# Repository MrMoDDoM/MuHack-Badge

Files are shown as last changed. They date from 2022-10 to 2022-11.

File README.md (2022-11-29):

# MuHack-Badge
Official repository for MuHack Badge.

The board features an RP2040 as main microcontroller running micropython.
Its job is to setup and stream data from the Bosh Sensor Hub BHI106B, as well as controlling the LEDs.

```Hardware/``` folder contains the KiCad project

```Software/``` folder contains the BOSS system and the sketch for the ESP32

TODOs:
 - [ ] Connect the interrupt line of BHI to the RP2040
 - [ ] Invert TX/RX of UART between ESP32 and RP2040
 - [ ] Change to a bigger footprint of ESP32 debug port
 - [ ] Maybe add two button for boot sel and reset for the ESP32
 - [ ] Change button battery footprint
 - [ ] Improve silkscreen text size
 - [ ] Add silkscreen label for many things (pinout, battery polarity, etc)
 - [ ] Expose BHI's internal I2C and interrupt line (for future sensors)
 - [ ] Move I2C pull-up resistor
 - [ ] Add led polarity
 - [ ] Remove power inductor (or change to an available one)
 - [ ] Maybe add a way to switch LEDs data line to the ESP32 instead of the RP2040
 - [ ] Docs and code comments
 - [ ] Remove the D16 Schottky Diode from the battery line
 
 Special Thanks to:
 @gcammisa and Paolino

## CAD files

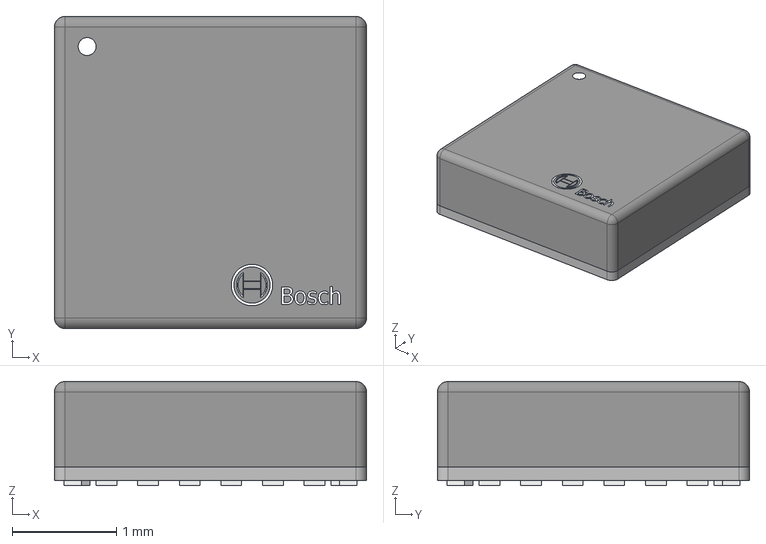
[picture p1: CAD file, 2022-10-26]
Hardware/IC_Bosch Sensortec_BHI160B/eec.models/Bosch_Sensortec_-_BHI160B.step
3.00 x 3.00 x 1.00 mm

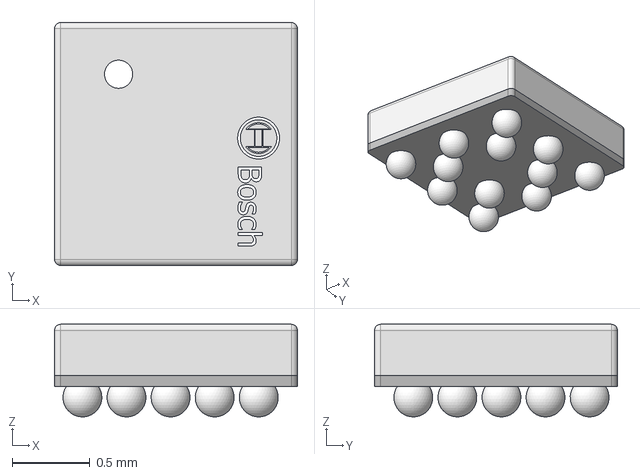
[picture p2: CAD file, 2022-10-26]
Hardware/IC_Bosch Sensortec_BMM150/eec.models/Bosch_Sensortec_-_BMM150.step
1.56 x 1.56 x 0.596 mm

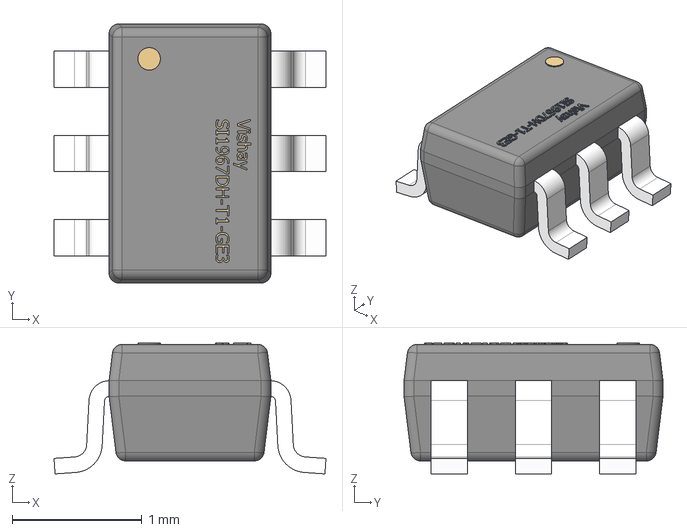
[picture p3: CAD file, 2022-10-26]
Hardware/Trans_Vishay_SI1967DH-T1-GE3/eec.models/Vishay_-_SI1967DH-T1-GE3.step
2.10 x 2.00 x 1.01 mm

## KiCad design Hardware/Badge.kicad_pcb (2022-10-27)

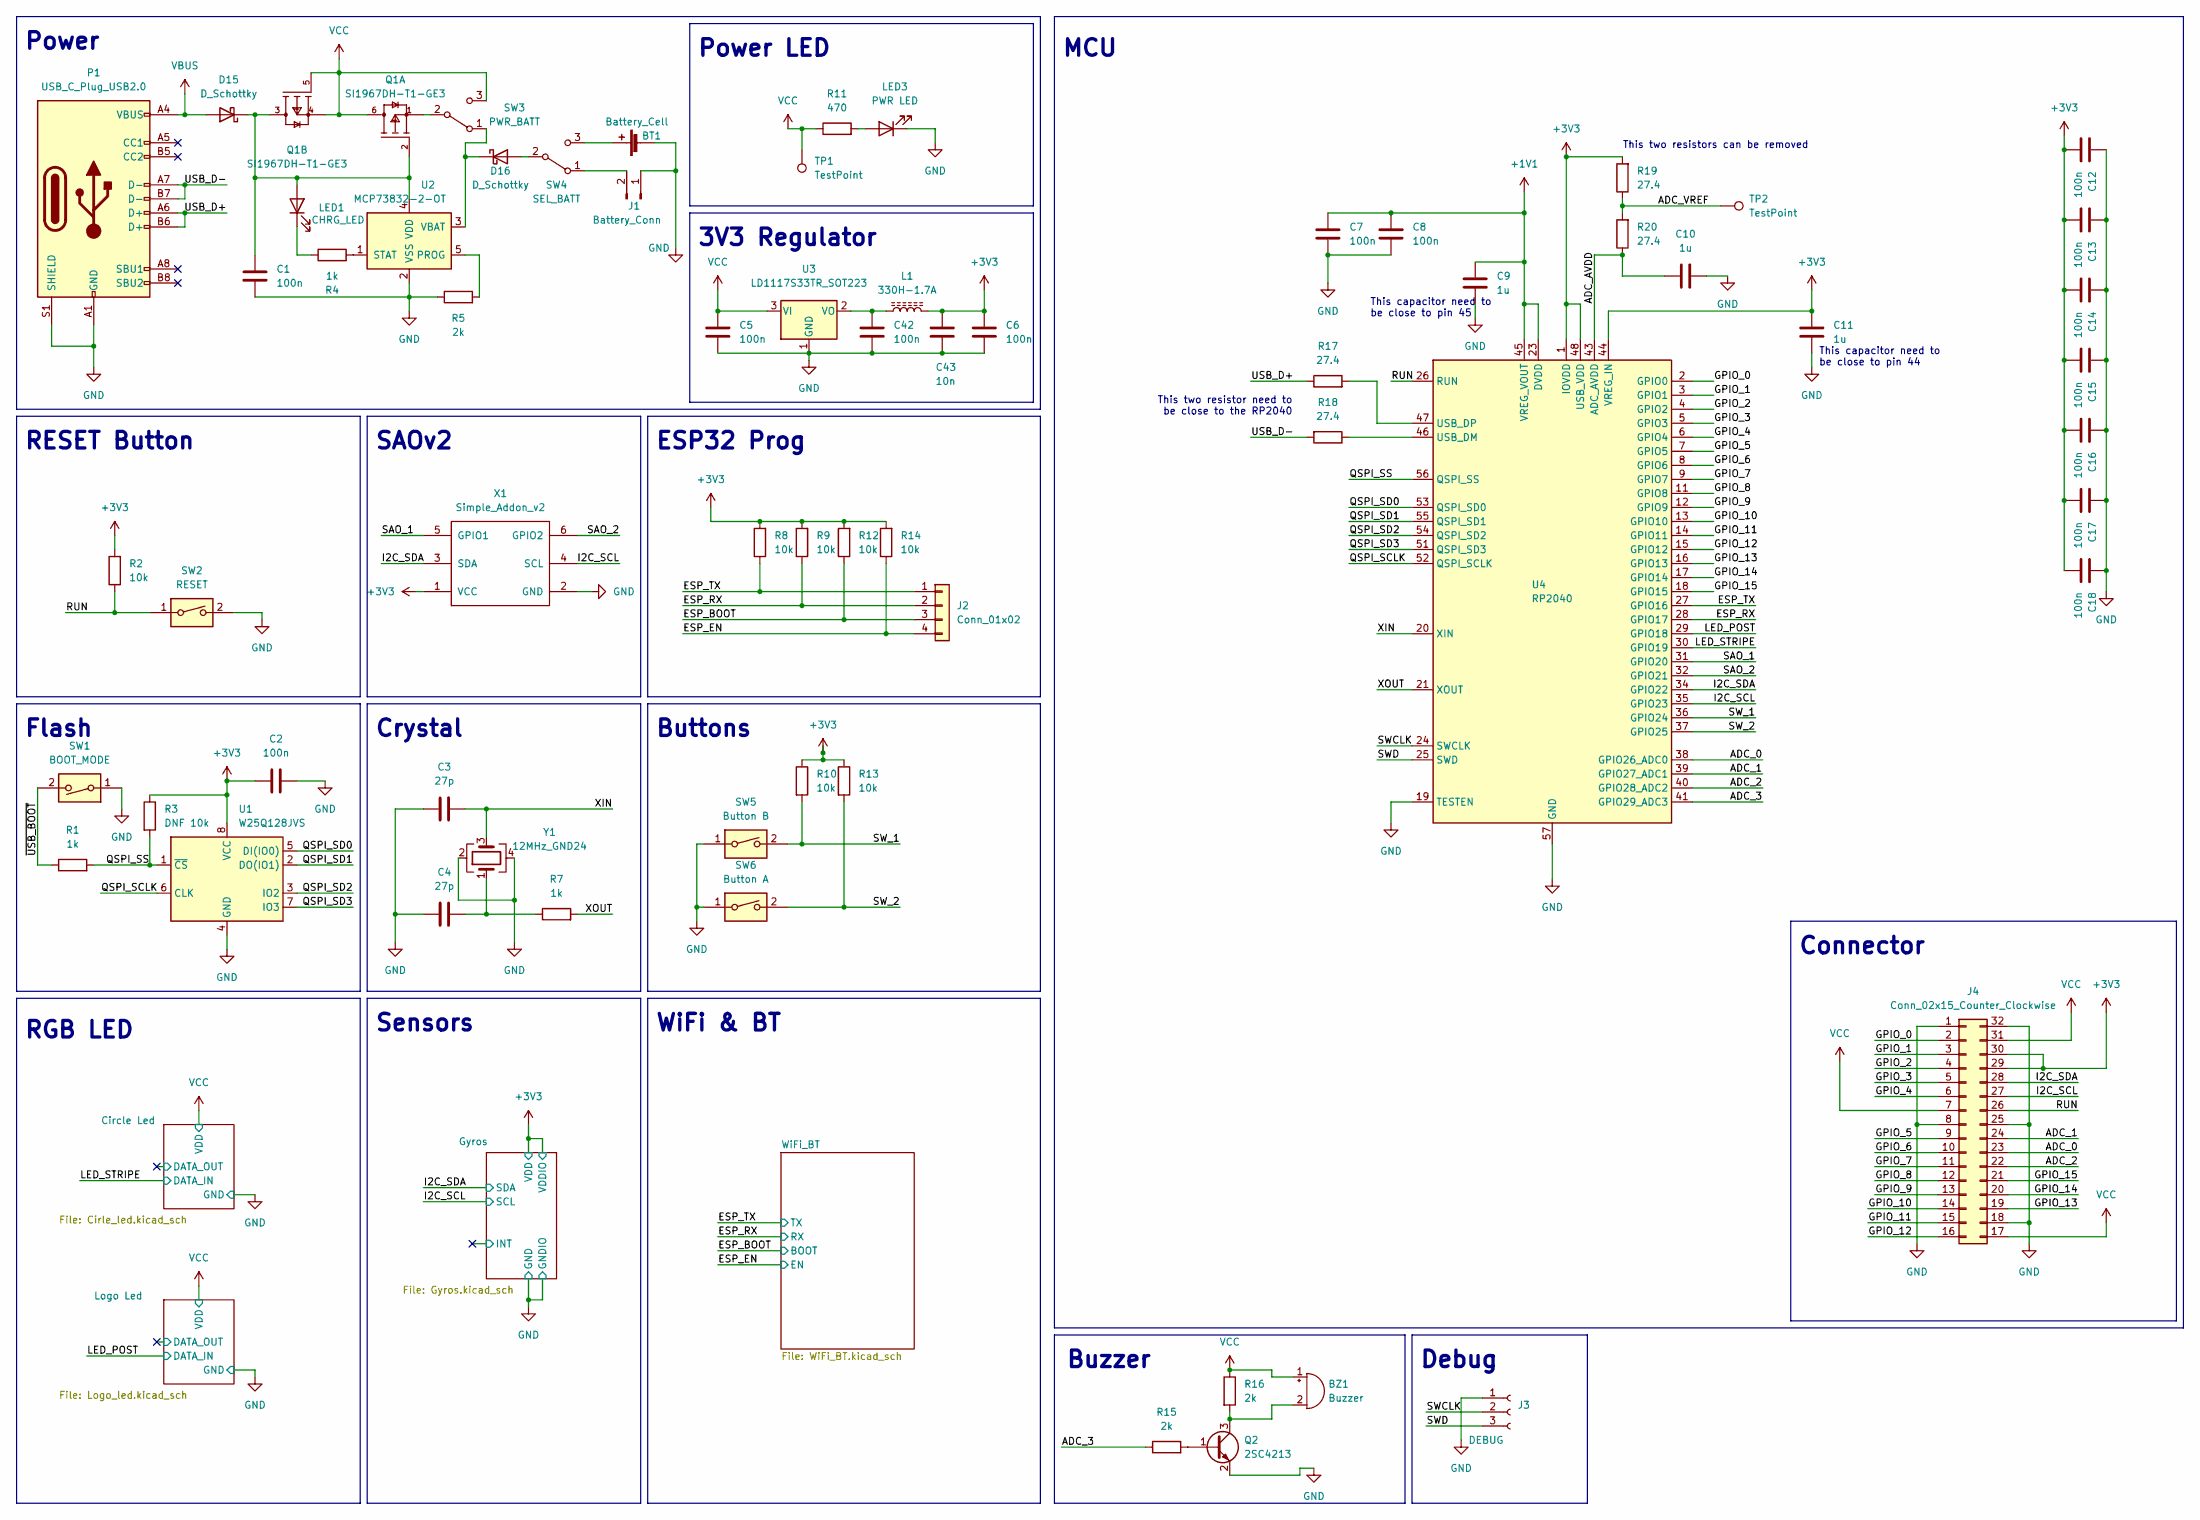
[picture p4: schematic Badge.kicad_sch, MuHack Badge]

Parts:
BT1: Battery_Cell; BatteryHolder_LINX_BAT-HLD-012-SMT
BZ1: Buzzer; Buzzer_Mallory_AST1109MLTRQ
C1, C2, C5, C6, C7, C8, C12, C13, C14, C15, C16, C17, C18, C42: 100n; C_0402_1005Metric
C3, C4: 27p; C_0402_1005Metric
C9, C10, C11: 1u; C_0402_1005Metric
C43: 10n; C_0402_1005Metric
D15, D16: D_Schottky; D_SMA
J1: Battery_Conn; JST_PH_B2B-PH-K_1x02_P2.00mm_Vertical
J2: Conn_01x02; PinSocket_1x04_P1.00mm_Vertical
J3: DEBUG; PinSocket_1x03_P2.54mm_Vertical
J4: Conn_02x15_Counter_Clockwise; PinSocket_2x16_P2.54mm_Vertical
L1: 330H-1.7A; L_0603_1608Metric
LED1: CHRG_LED; LED_0603_1608Metric
LED3: PWR LED; LED_0603_1608Metric
P1: USB_C_Plug_USB2.0; USB_C_Receptacle_Palconn_UTC16-G
Q1: SI1967DH-T1-GE3; Vishay-S-03946-07_2001-B-0; mouser part number 781-SI1967DH-T1-GE3; digikey description MOSFET 2P-CH 20V 1.3A SC70-6
Q2: 2SC4213; SOT-323_SC-70
R1, R4, R7: 1k; R_0402_1005Metric
R2, R8, R9, R10, R12, R13, R14: 10k; R_0402_1005Metric
R3: DNF 10k; R_0402_1005Metric
R5, R15, R16: 2k; R_0402_1005Metric
R11: 470; R_0402_1005Metric
R17, R18, R19, R20: 27.4; R_0402_1005Metric
SW1: BOOT_MODE; TS-1187A-B-A-B
SW2: RESET; TS-1187A-B-A-B
SW3: PWR_BATT; SW_SPDT_CK-JS102011SAQN
SW4: SEL_BATT; SW_SPDT_CK-JS102011SAQN
SW5: Button B; TS-1187A-B-A-B
SW6: Button A; TS-1187A-B-A-B
TP1, TP2: TestPoint; TestPoint_Pad_D1.0mm
U1: W25Q128JVS; SOIC-8_5.23x5.23mm_P1.27mm
U2: MCP73832-2-OT; SOT-23-5
U3: LD1117S33TR_SOT223; SOT-223-3_TabPin2
U4: RP2040; QFN-56-1EP_7x7mm_P0.4mm_EP3.2x3.2mm
X1: Simple_Addon_v2; Simple_Addon_v2-BADGE-2x3
Y1: 12MHz_GND24; Crystal_SMD_3225-4Pin_3.2x2.5mm

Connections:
+1V1: C7.1, C8.1, C9.2, U4.23 (DVDD), U4.45 (VREG_VOUT), U4.50 (DVDD)
+3V3: C2.1, C6.2, C11.1, C12.2, C13.2, C14.2, C15.2, C16.2, C17.2, C18.2, C43.2, J4.29, J4.30, L1.2, R2.2, R3.1, R8.2, R9.2, R10.1, R12.2, R13.1, R14.2, R19.2, U1.8 (VCC), U4.1 (IOVDD), U4.10 (IOVDD), U4.22 (IOVDD), U4.33 (IOVDD), U4.42 (IOVDD), U4.44 (VREG_IN), U4.48 (USB_VDD), U4.49 (IOVDD), X1.1 (VCC); also elsewhere on the board
/ADC_0: J4.23, U4.38 (GPIO26_ADC0)
/ADC_1: J4.24, U4.39 (GPIO27_ADC1)
/ADC_2: J4.22, U4.40 (GPIO28_ADC2)
/ADC_3: R15.1, U4.41 (GPIO29_ADC3)
/ADC_AVDD: C10.1, R20.1, U4.43 (ADC_AVDD)
/ADC_VREF: R19.1, R20.2, TP2.1
/ESP_BOOT: J2.3, R12.1; also elsewhere on the board
/ESP_EN: J2.4, R14.1; also elsewhere on the board
/ESP_RX: J2.2, R9.1, U4.28 (GPIO17); also elsewhere on the board
/ESP_TX: J2.1, R8.1, U4.27 (GPIO16); also elsewhere on the board
/GPIO_0: J4.2, U4.2 (GPIO0)
/GPIO_1: J4.3, U4.3 (GPIO1)
/GPIO_2: J4.4, U4.4 (GPIO2)
/GPIO_3: J4.5, U4.5 (GPIO3)
/GPIO_4: J4.6, U4.6 (GPIO4)
/GPIO_5: J4.9, U4.7 (GPIO5)
/GPIO_6: J4.10, U4.8 (GPIO6)
/GPIO_7: J4.11, U4.9 (GPIO7)
/GPIO_8: J4.12, U4.11 (GPIO8)
/GPIO_9: J4.13, U4.12 (GPIO9)
/GPIO_10: J4.14, U4.13 (GPIO10)
/GPIO_11: J4.15, U4.14 (GPIO11)
/GPIO_12: J4.16, U4.15 (GPIO12)
/GPIO_13: J4.19, U4.16 (GPIO13)
/GPIO_14: J4.20, U4.17 (GPIO14)
/GPIO_15: J4.21, U4.18 (GPIO15)
/I2C_SCL: J4.27, U4.35 (GPIO23), X1.4 (SCL); also elsewhere on the board
/I2C_SDA: J4.28, U4.34 (GPIO22), X1.3 (SDA); also elsewhere on the board
/LED_POST: U4.29 (GPIO18); also elsewhere on the board
/LED_STRIPE: U4.30 (GPIO19); also elsewhere on the board
/QSPI_SCLK: U1.6 (CLK), U4.52 (QSPI_SCLK)
/QSPI_SD0: U1.5 (DI(IO0)), U4.53 (QSPI_SD0)
/QSPI_SD1: U1.2 (DO(IO1)), U4.55 (QSPI_SD1)
/QSPI_SD2: U1.3 (IO2), U4.54 (QSPI_SD2)
/QSPI_SD3: U1.7 (IO3), U4.51 (QSPI_SD3)
/QSPI_SS: R1.2, R3.2, U1.1 (~CS), U4.56 (QSPI_SS)
/RUN: J4.26, R2.1, SW2.1, U4.26 (RUN)
/SAO_1: U4.31 (GPIO20), X1.5 (GPIO1)
/SAO_2: U4.32 (GPIO21), X1.6 (GPIO2)
/SWCLK: J3.2, U4.24 (SWCLK)
/SWD: J3.3, U4.25 (SWD)
/SW_1: R10.2, SW5.2, U4.36 (GPIO24)
/SW_2: R13.2, SW6.2, U4.37 (GPIO25)
/USB_D+: P1.A6 (D+), P1.B6 (D+), R17.1
/USB_D-: P1.A7 (D-), P1.B7 (D-), R18.2
/XIN: C3.2, U4.20 (XIN), Y1.3
/XOUT: R7.2, U4.21 (XOUT)
/~USB_BOOT: R1.1, SW1.2
GND: BT1.2 (-), C1.2, C2.2, C3.1, C4.1, C5.1, C6.1, C7.2, C8.2, C9.1, C10.2, C11.2, C12.1, C13.1, C14.1, C15.1, C16.1, C17.1, C18.1, C42.1, C43.1, J1.1, J3.1, J4.1, J4.8, J4.18, J4.25, J4.32, LED3.1 (K), P1.A1 (GND), P1.A12 (GND), P1.B1 (GND), P1.B12 (GND), P1.S1 (SHIELD), Q2.2 (E), R5.1, SW1.1, SW2.2, SW5.1, SW6.1, U1.4 (GND), U2.2 (VSS), U3.1 (GND), U4.19 (TESTEN), U4.57 (GND), X1.2 (GND), Y1.2, Y1.4; also elsewhere on the board
unnamed: BT1.1 (+), SW4.3 (C)
unnamed: BZ1.2 (+), Q2.3 (C), R16.2
unnamed: C1.1, D15.1 (K), LED1.2 (A), Q1.2 (G1), Q1.3 (D2), U2.4 (VDD)
unnamed: C4.2, R7.1, Y1.1
unnamed: C42.2, L1.1, U3.2 (VO)
unnamed: D16.1 (K), SW3.1 (A), U2.3 (VBAT)
unnamed: D16.2 (A), SW4.2 (B)
unnamed: J1.2, SW4.1 (A)
unnamed: LED1.1 (K), R4.1
unnamed: LED3.2 (A), R11.2
unnamed: Q1.1 (S1), SW3.2 (B)
unnamed: Q2.1 (B), R15.2
unnamed: R4.2, U2.1 (STAT)
unnamed: R5.2, U2.5 (PROG)
unnamed: R17.2, U4.47 (USB_DP)
unnamed: R18.1, U4.46 (USB_DM)
VBUS: D15.2 (A), P1.A4 (VBUS), P1.A9 (VBUS), P1.B4 (VBUS), P1.B9 (VBUS)
VCC: BZ1.1 (-), C5.2, J4.7, J4.17, J4.31, Q1.4 (S2), Q1.5 (G2), Q1.6 (D1), R11.1, R16.1, SW3.3 (C), TP1.1, U3.3 (VI); also elsewhere on the board

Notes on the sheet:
This capacitor need to be close to pin 44
Buttons
Power
This two resistor need to be close to the RP2040
ESP32 Prog
3V3 Regulator
Crystal
Power LED
This capacitor need to be close to pin 45
RESET Button
This two resistors can be removed
WiFi & BT
Connector
SAOv2
Buzzer
Flash
Debug
Sensors
MCU
RGB LED

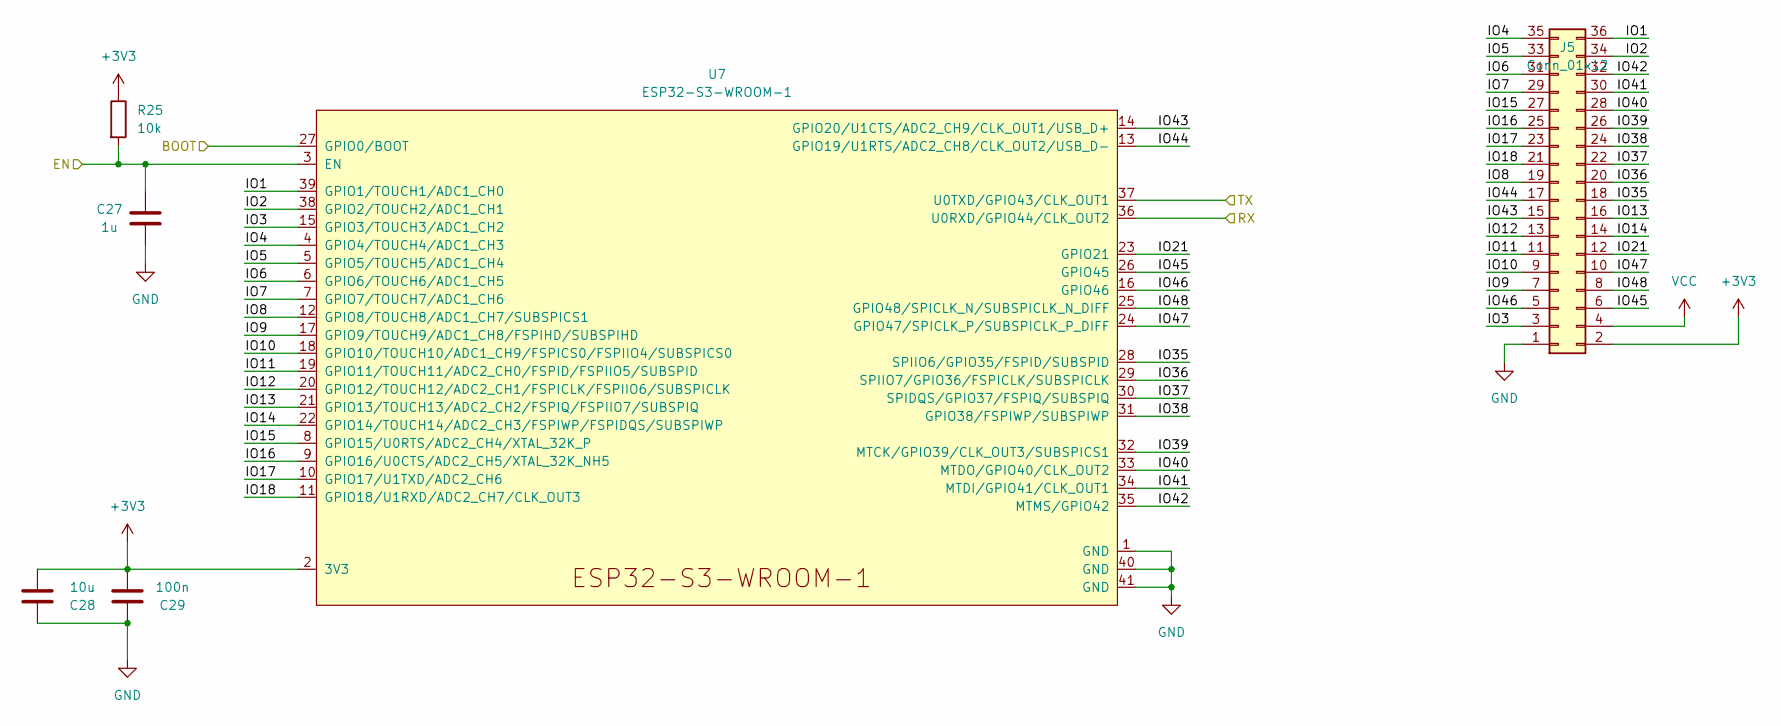
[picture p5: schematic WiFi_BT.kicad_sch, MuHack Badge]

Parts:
C27: 1u; C_0402_1005Metric
C28: 10u; C_0402_1005Metric
C29: 100n; C_0402_1005Metric
J5: Conn_01x12; PinSocket_2x18_P1.27mm_Vertical
R25: 10k; R_0402_1005Metric
U7: ESP32-S3-WROOM-1

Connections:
+3V3: C28.1, C29.1, J5.2, R25.1, U7.2 (3V3); also elsewhere on the board
/ESP_BOOT: U7.27 (GPIO0/BOOT); also elsewhere on the board
/ESP_EN: C27.2, R25.2, U7.3 (EN); also elsewhere on the board
/ESP_RX: U7.36 (U0RXD/GPIO44/CLK_OUT2); also elsewhere on the board
/ESP_TX: U7.37 (U0TXD/GPIO43/CLK_OUT1); also elsewhere on the board
/WiFi_BT/IO1: J5.36, U7.39 (GPIO1/TOUCH1/ADC1_CH0)
/WiFi_BT/IO2: J5.34, U7.38 (GPIO2/TOUCH2/ADC1_CH1)
/WiFi_BT/IO3: J5.3, U7.15 (GPIO3/TOUCH3/ADC1_CH2)
/WiFi_BT/IO4: J5.35, U7.4 (GPIO4/TOUCH4/ADC1_CH3)
/WiFi_BT/IO5: J5.33, U7.5 (GPIO5/TOUCH5/ADC1_CH4)
/WiFi_BT/IO6: J5.31, U7.6 (GPIO6/TOUCH6/ADC1_CH5)
/WiFi_BT/IO7: J5.29, U7.7 (GPIO7/TOUCH7/ADC1_CH6)
/WiFi_BT/IO8: J5.19, U7.12 (GPIO8/TOUCH8/ADC1_CH7/SUBSPICS1)
/WiFi_BT/IO9: J5.7, U7.17 (GPIO9/TOUCH9/ADC1_CH8/FSPIHD/SUBSPIHD)
/WiFi_BT/IO10: J5.9, U7.18 (GPIO10/TOUCH10/ADC1_CH9/FSPICS0/FSPIIO4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)
/WiFi_BT/IO11: J5.11, U7.19 (GPIO11/TOUCH11/ADC2_CH0/FSPID/FSPIIO5/S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)
/WiFi_BT/IO12: J5.13, U7.20 (GPIO12/TOUCH12/ADC2_CH1/FSPICLK/FSPIIO6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)
/WiFi_BT/IO13: J5.16, U7.21 (GPIO13/TOUCH13/ADC2_CH2/FSPIQ/FSPIIO7/S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)
/WiFi_BT/IO14: J5.14, U7.22 (GPIO14/TOUCH14/ADC2_CH3/FSPIWP/FSPIDQS/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)
/WiFi_BT/IO15: J5.27, U7.8 (GPIO15/U0RTS/ADC2_CH4/XTAL_32K_P)
/WiFi_BT/IO16: J5.25, U7.9 (GPIO16/U0CTS/ADC2_CH5/XTAL_32K_NH5)
/WiFi_BT/IO17: J5.23, U7.10 (GPIO17/U1TXD/ADC2_CH6)
/WiFi_BT/IO18: J5.21, U7.11 (GPIO18/U1RXD/ADC2_CH7/CLK_OUT3)
/WiFi_BT/IO21: J5.12, U7.23 (GPIO21)
/WiFi_BT/IO35: J5.18, U7.28 (SPIIO6/GPIO35/FSPID/SUBSPID)
/WiFi_BT/IO36: J5.20, U7.29 (SPIIO7/GPIO36/FSPICLK/SUBSPICLK)
/WiFi_BT/IO37: J5.22, U7.30 (SPIDQS/GPIO37/FSPIQ/SUBSPIQ)
/WiFi_BT/IO38: J5.24, U7.31 (GPIO38/FSPIWP/SUBSPIWP)
/WiFi_BT/IO39: J5.26, U7.32 (MTCK/GPIO39/CLK_OUT3/SUBSPICS1)
/WiFi_BT/IO40: J5.28, U7.33 (MTDO/GPIO40/CLK_OUT2)
/WiFi_BT/IO41: J5.30, U7.34 (MTDI/GPIO41/CLK_OUT1)
/WiFi_BT/IO42: J5.32, U7.35 (MTMS/GPIO42)
/WiFi_BT/IO43: J5.15, U7.14 (GPIO20/U1CTS/ADC2_CH9/CLK_OUT1/USB_D+)
/WiFi_BT/IO44: J5.17, U7.13 (GPIO19/U1RTS/ADC2_CH8/CLK_OUT2/USB_D-)
/WiFi_BT/IO45: J5.6, U7.26 (GPIO45)
/WiFi_BT/IO46: J5.5, U7.16 (GPIO46)
/WiFi_BT/IO47: J5.10, U7.24 (GPIO47/SPICLK_P/SUBSPICLK_P_DIFF)
/WiFi_BT/IO48: J5.8, U7.25 (GPIO48/SPICLK_N/SUBSPICLK_N_DIFF)
GND: C27.1, C28.2, C29.2, J5.1, U7.1 (GND), U7.40 (GND), U7.41 (GND); also elsewhere on the board
VCC: J5.4; also elsewhere on the board

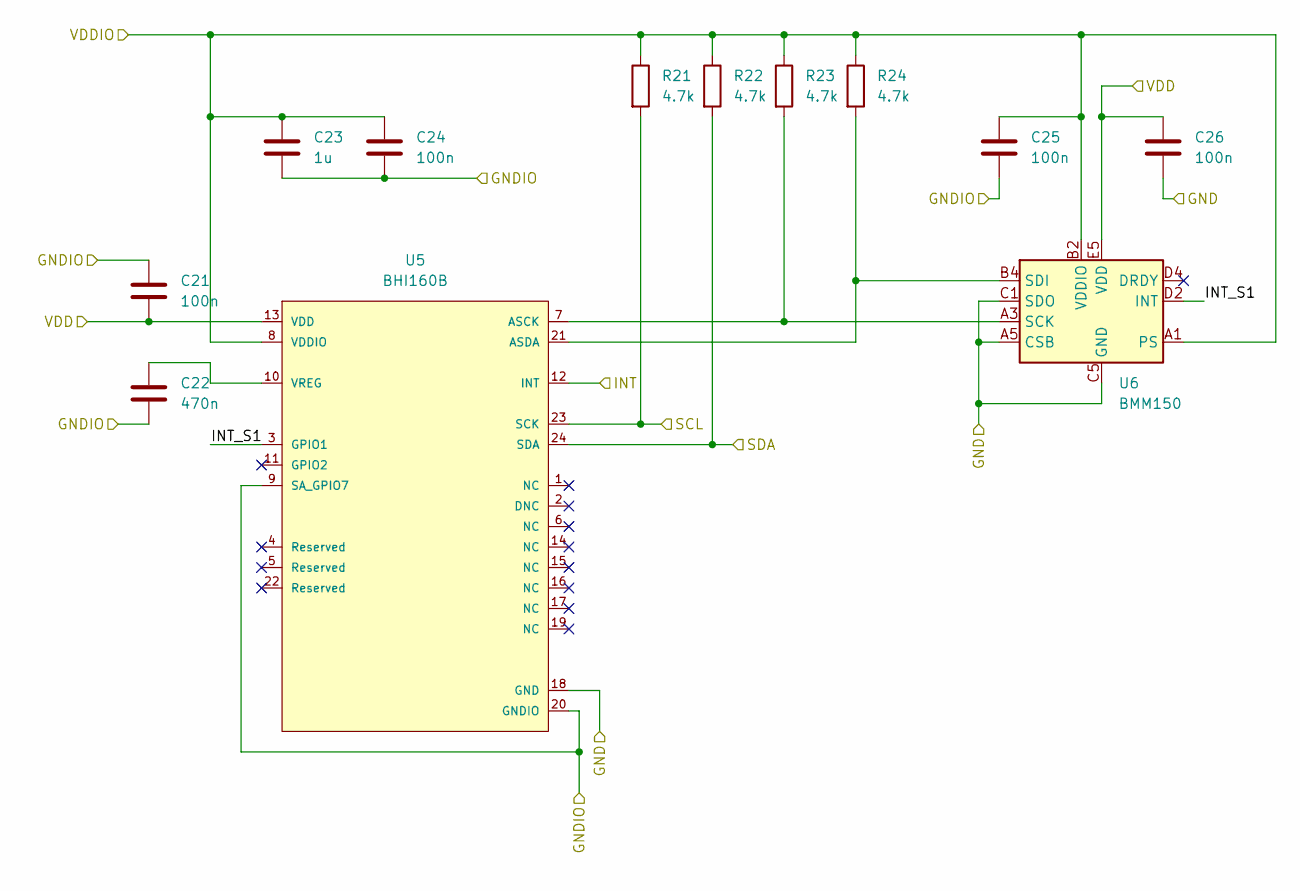
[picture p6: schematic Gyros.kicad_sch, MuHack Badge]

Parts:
C21, C24, C25, C26: 100n; C_0402_1005Metric
C22: 470n; C_0402_1005Metric
C23: 1u; C_0402_1005Metric
R21, R22, R23, R24: 4.7k; R_0402_1005Metric
U5: BHI160B; Bosch_Sensortec-BHI160B-MFG; mouser part number 262-BHI160B; digikey description IMU ACCEL/GYRO 3-AXIS I2C 24LGA
U6: BMM150; Bosch_Sensortec-BMM150-IPC_B

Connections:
+3V3: C21.2, C23.1, C24.1, C25.2, C26.2, R21.1, R22.1, R23.1, R24.1, U5.8 (VDDIO), U5.13 (VDD), U6.A1 (PS), U6.B2 (VDDIO), U6.E5 (VDD); also elsewhere on the board
/Gyros/INT: U5.12 (INT)
/Gyros/INT_S1: U5.3 (GPIO1), U6.D2 (INT)
/I2C_SCL: R21.2, U5.23 (SCK); also elsewhere on the board
/I2C_SDA: R22.2, U5.24 (SDA); also elsewhere on the board
GND: C21.1, C22.2, C23.2, C24.2, C25.1, C26.1, U5.9 (SA_GPIO7), U5.18 (GND), U5.20 (GNDIO), U6.A5 (CSB), U6.C1 (SDO), U6.C5 (GND), U6.E1 (GND), U6.E3 (GND); also elsewhere on the board
unnamed: C22.1, U5.10 (VREG)
unnamed: R23.2, U5.7 (ASCK), U6.A3 (SCK)
unnamed: R24.2, U5.21 (ASDA), U6.B4 (SDI)

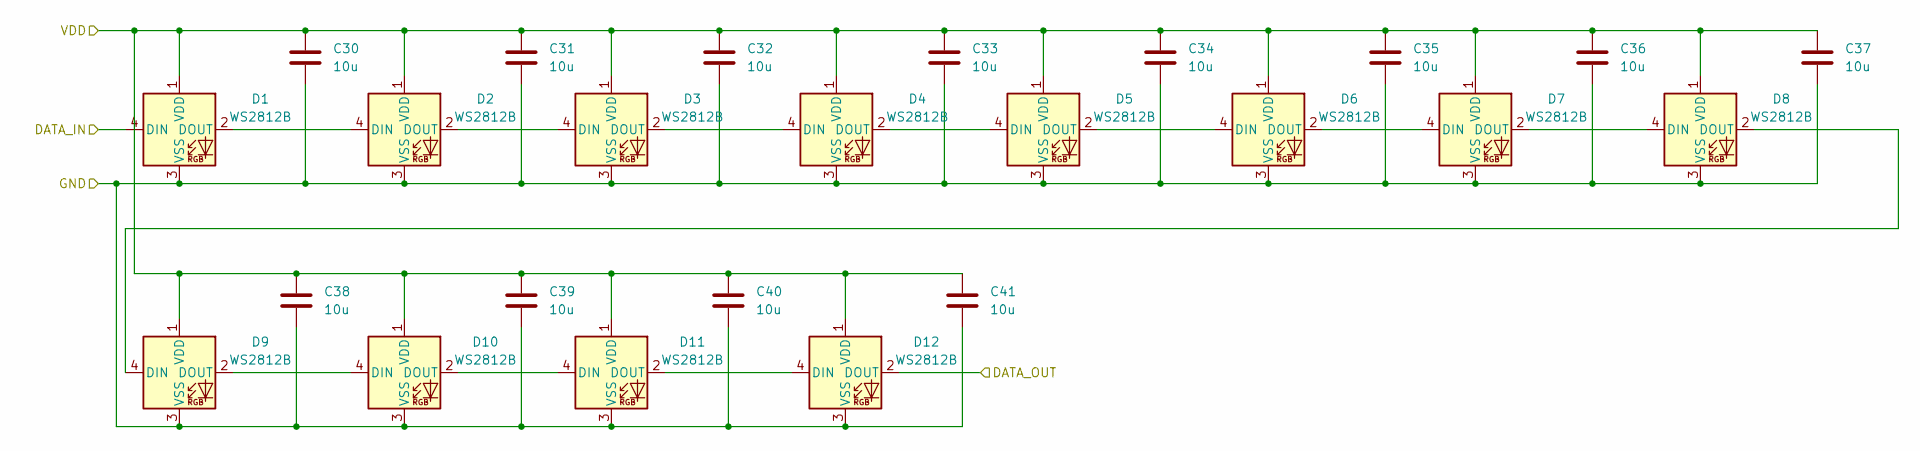
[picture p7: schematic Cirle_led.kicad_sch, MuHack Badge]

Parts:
C30, C31, C32, C33, C34, C35, C36, C37, C38, C39, C40, C41: 10u; C_0402_1005Metric
D1, D2, D3, D4, D5, D6, D7, D8, D9, D10, D11, D12: WS2812B; LED_WS2812B_PLCC4_5.0x5.0mm_P3.2mm

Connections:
/Circle Led/DATA_OUT: D12.2 (DOUT)
/LED_STRIPE: D1.4 (DIN); also elsewhere on the board
GND: C30.2, C31.2, C32.2, C33.2, C34.2, C35.2, C36.2, C37.2, C38.2, C39.2, C40.2, C41.2, D1.3 (VSS), D2.3 (VSS), D3.3 (VSS), D4.3 (VSS), D5.3 (VSS), D6.3 (VSS), D7.3 (VSS), D8.3 (VSS), D9.3 (VSS), D10.3 (VSS), D11.3 (VSS), D12.3 (VSS); also elsewhere on the board
unnamed: D1.2 (DOUT), D2.4 (DIN)
unnamed: D2.2 (DOUT), D3.4 (DIN)
unnamed: D3.2 (DOUT), D4.4 (DIN)
unnamed: D4.2 (DOUT), D5.4 (DIN)
unnamed: D5.2 (DOUT), D6.4 (DIN)
unnamed: D6.2 (DOUT), D7.4 (DIN)
unnamed: D7.2 (DOUT), D8.4 (DIN)
unnamed: D8.2 (DOUT), D9.4 (DIN)
unnamed: D10.2 (DOUT), D11.4 (DIN)
unnamed: D9.2 (DOUT), D10.4 (DIN)
unnamed: D11.2 (DOUT), D12.4 (DIN)
VCC: C30.1, C31.1, C32.1, C33.1, C34.1, C35.1, C36.1, C37.1, C38.1, C39.1, C40.1, C41.1, D1.1 (VDD), D2.1 (VDD), D3.1 (VDD), D4.1 (VDD), D5.1 (VDD), D6.1 (VDD), D7.1 (VDD), D8.1 (VDD), D9.1 (VDD), D10.1 (VDD), D11.1 (VDD), D12.1 (VDD); also elsewhere on the board

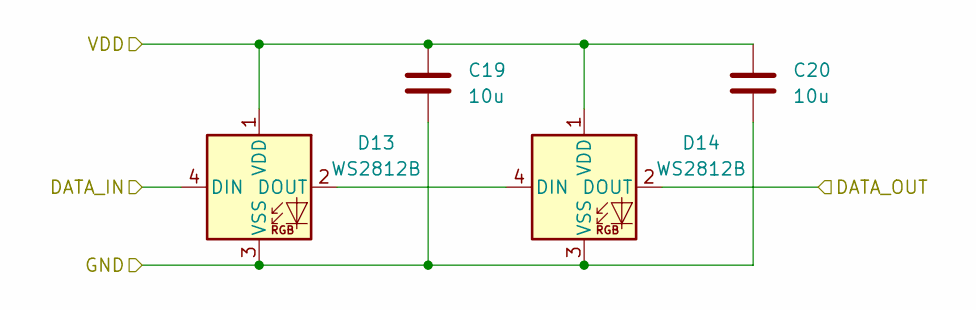
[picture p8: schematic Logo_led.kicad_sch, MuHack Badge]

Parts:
C19, C20: 10u; C_0402_1005Metric
D13, D14: WS2812B; LED_WS2812B_PLCC4_5.0x5.0mm_P3.2mm

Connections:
/LED_POST: D13.4 (DIN); also elsewhere on the board
/Logo Led/DATA_OUT: D14.2 (DOUT)
GND: C19.2, C20.2, D13.3 (VSS), D14.3 (VSS); also elsewhere on the board
unnamed: D13.2 (DOUT), D14.4 (DIN)
VCC: C19.1, C20.1, D13.1 (VDD), D14.1 (VDD); also elsewhere on the board

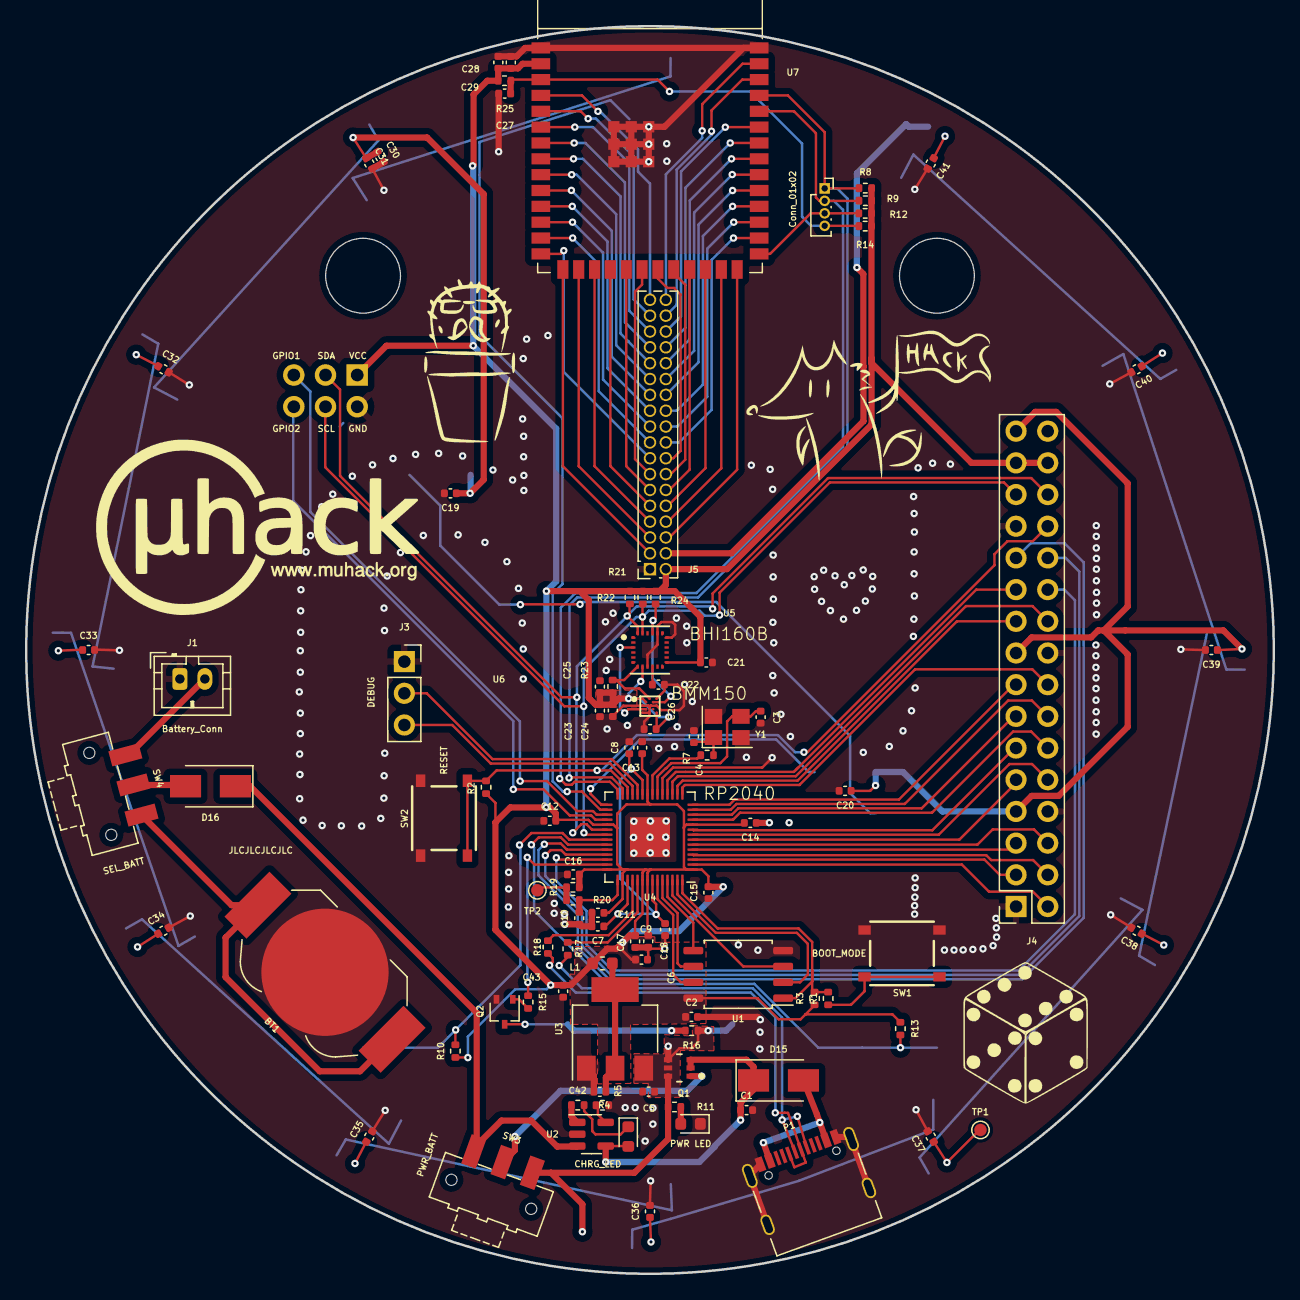
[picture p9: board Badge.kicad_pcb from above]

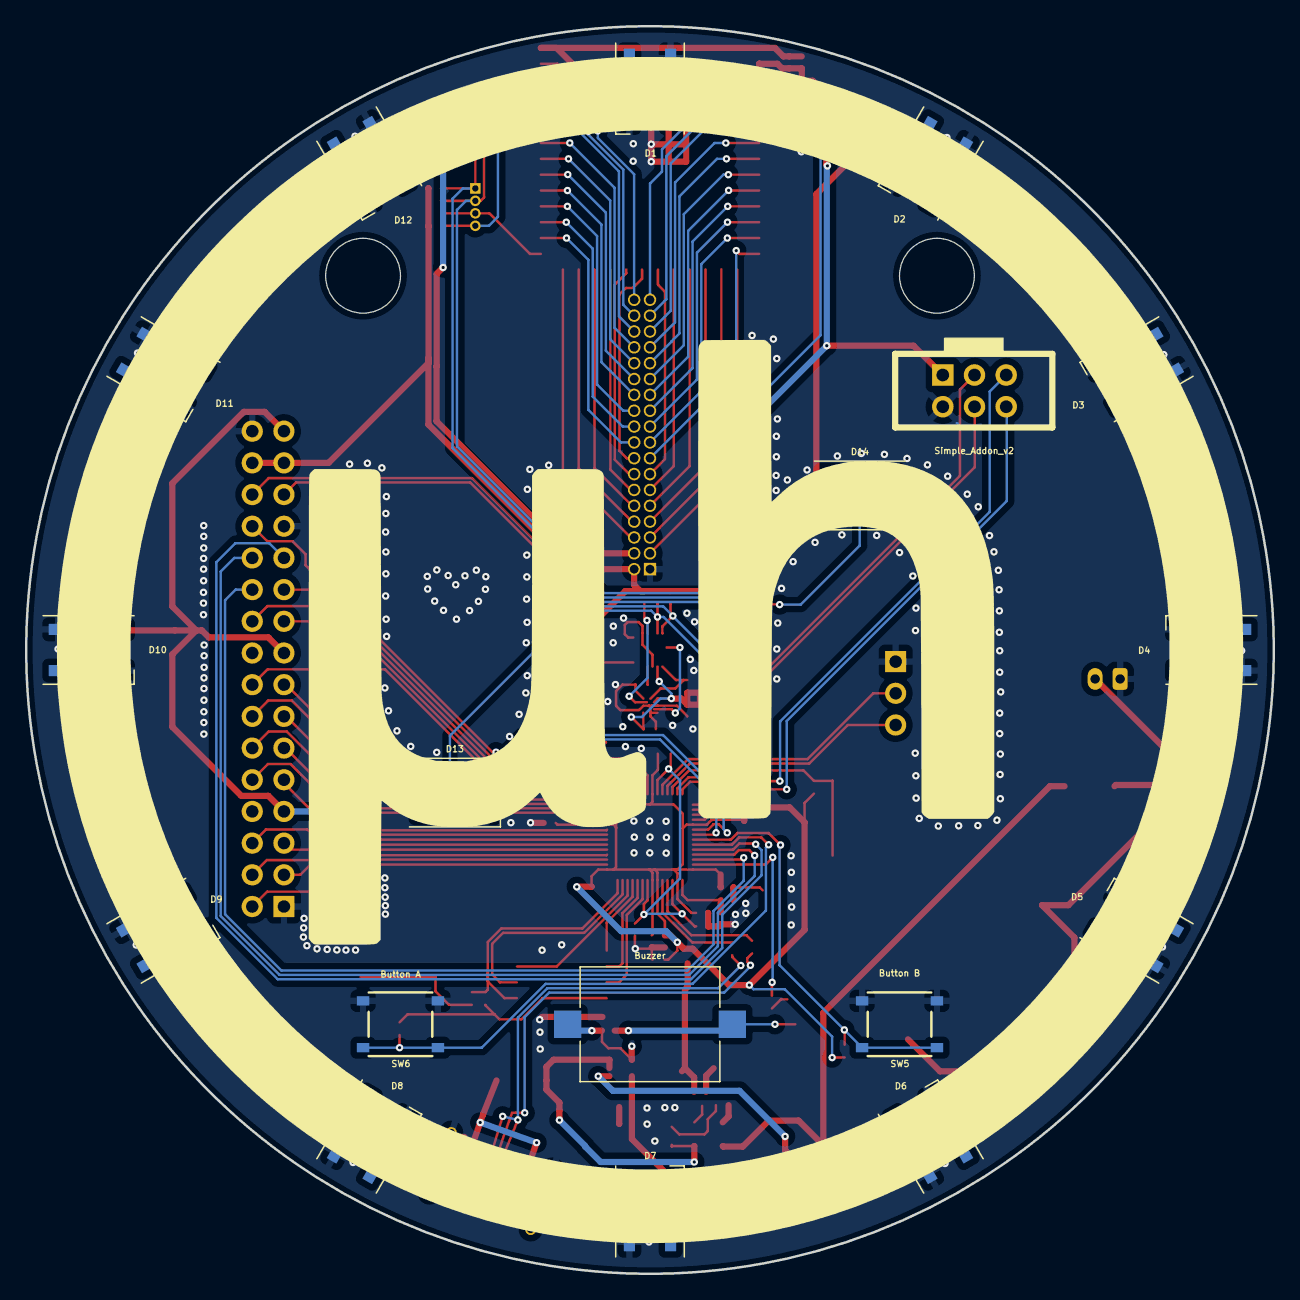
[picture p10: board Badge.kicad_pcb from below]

Board: 2 copper layers, 100.0 x 100.0 mm, 113 parts (18 on the bottom side), 118 nets.

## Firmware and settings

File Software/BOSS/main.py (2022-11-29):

import sys
from time import sleep_ms
from machine import I2C, Pin, PWM, UART
from buzzer_music.buzzer_music import music
import binascii
import neopixel
import _thread
import gc
#import micropython
import random
import select
from BHY.bhy import BHY
from CLED.cled import CLED

BOSS_Version = "1.0_beta"

applications = []

ESP_TX_PIN = 0
ESP_RX_PIN = 1

LED_LETTER_PIN = 18
LED_LETTER_LEN = 2

LED_STRIPE_PIN = 19
LED_STRIPE_LEN = 12

BUZZER_PIN = 29

BUTTON_A_PIN = 25
BUTTON_B_PIN = 24

SCL_PIN = 23
SDA_PIN = 22
BHY_I2C_ADDR = 0x28 # 40 in decimal

CLED_THREAD = 0

button_A = machine.Pin(BUTTON_A_PIN, Pin.IN)
button_B = machine.Pin(BUTTON_B_PIN, Pin.IN)

bhy = BHY(sda=SDA_PIN, scl=SCL_PIN, address=BHY_I2C_ADDR, stand_alone=False, debug=False)
cled = CLED(LED_STRIPE_PIN, LED_STRIPE_LEN, LED_LETTER_PIN, LED_LETTER_LEN, debug=False)

song = '0 E3 1 0;2 E4 1 0;4 E3 1 0;6 E4 1 0;8 E3 1 0;10 E4 1 0;12 E3 1 0;14 E4 1 0;16 A3 1 0;18 A4 1 0;20 A3 1 0;22 A4 1 0;24 A3 1 0;26 A4 1 0;28 A3 1 0;30 A4 1 0;32 G#3 1 0;34 G#4 1 0;36 G#3 1 0;38 G#4 1 0;40 E3 1 0;42 E4 1 0;44 E3 1 0;46 E4 1 0;48 A3 1 0;50 A4 1 0;52 A3 1 0;54 A4 1 0;56 A3 1 0;58 B3 1 0;60 C4 1 0;62 D4 1 0;64 D3 1 0;66 D4 1 0;68 D3 1 0;70 D4 1 0;72 D3 1 0;74 D4 1 0;76 D3 1 0;78 D4 1 0;80 C3 1 0;82 C4 1 0;84 C3 1 0;86 C4 1 0;88 C3 1 0;90 C4 1 0;92 C3 1 0;94 C4 1 0;96 G2 1 0;98 G3 1 0;100 G2 1 0;102 G3 1 0;104 E3 1 0;106 E4 1 0;108 E3 1 0;110 E4 1 0;114 A4 1 0;112 A3 1 0;116 A3 1 0;118 A4 1 0;120 A3 1 0;122 A4 1 0;124 A3 1 0;0 E6 1 1;4 B5 1 1;6 C6 1 1;8 D6 1 1;10 E6 1 1;11 D6 1 1;12 C6 1 1;14 B5 1 1;0 E5 1 6;4 B4 1 6;6 C5 1 6;8 D5 1 6;10 E5 1 6;11 D5 1 6;12 C5 1 6;14 B4 1 6;16 A5 1 1;20 A5 1 1;22 C6 1 1;24 E6 1 1;28 D6 1 1;30 C6 1 1;32 B5 1 1;36 B5 1 1;36 B5 1 1;37 B5 1 1;38 C6 1 1;40 D6 1 1;44 E6 1 1;48 C6 1 1;52 A5 1 1;56 A5 1 1;20 A4 1 6;16 A4 1 6;22 C5 1 6;24 E5 1 6;28 D5 1 6;30 C5 1 6;32 B4 1 6;36 B4 1 6;37 B4 1 6;38 C5 1 6;40 D5 1 6;44 E5 1 6;48 C5 1 6;52 A4 1 6;56 A4 1 6;64 D5 1 6;64 D6 1 1;68 D6 1 1;70 F6 1 1;72 A6 1 1;76 G6 1 1;78 F6 1 1;80 E6 1 1;84 E6 1 1;86 C6 1 1;88 E6 1 1;92 D6 1 1;94 C6 1 1;96 B5 1 1;100 B5 1 1;101 B5 1 1;102 C6 1 1;104 D6 1 1;108 E6 1 1;112 C6 1 1;116 A5 1 1;120 A5 1 1;72 A5 1 6;80 E5 1 6;68 D5 1 7;70 F5 1 7;76 G5 1 7;84 E5 1 7;78 F5 1 7;86 C5 1 7;88 E5 1 6;96 B4 1 6;104 D5 1 6;112 C5 1 6;120 A4 1 6;92 D5 1 7;94 C5 1 7;100 B4 1 7;101 B4 1 7;102 C5 1 7;108 E5 1 7;116 A4 1 7'
sensor_config = []
bhy_upload_try = 3
one_shot_re_enable = [BHY.VS_TYPE_WAKEUP,
                      BHY.VS_TYPE_WAKEUP + BHY.BHY_SID_WAKEUP_OFFSET,
                      BHY.VS_TYPE_GLANCE,
                      BHY.VS_TYPE_GLANCE + BHY.BHY_SID_WAKEUP_OFFSET,
                      BHY.VS_TYPE_PICKUP,
                      BHY.VS_TYPE_PICKUP + BHY.BHY_SID_WAKEUP_OFFSET]

#   | X | Y | Z |
# Xs| 1 | 0 | 0 |
# Ys| 0 | -1| 0 |
# Zs| 0 | 0 | -1|

#remapping_matrix = [0,1,0,1,0,0,0,0,-1] # P5 ?
#remapping_matrix = [1,0,0,0,-1,0,0,0,-1] # P7 ?
remapping_matrix = [1,0,0,0,1,0,0,0,-1] # P? ? - obtained from experimenting with the accelerometer

def testHardware():
    led_stripe = neopixel.NeoPixel(machine.Pin(LED_STRIPE_PIN), LED_STRIPE_LEN)
    led_letter = neopixel.NeoPixel(machine.Pin(LED_LETTER_PIN), LED_LETTER_LEN)
    try:
        print("Testing LED Stripe")
        for j in range(255):
            for i in range(LED_STRIPE_LEN):
                rc_index = (i * 256 // LED_STRIPE_LEN) + j
                led_stripe[i] = cled.wheel(rc_index & 255)
            led_stripe.write()
            sleep_ms(10)

        print("Testing LED on Letters")
        for j in range(255):
            for i in range(LED_LETTER_LEN):
                rc_index = (i * 256 // LED_LETTER_LEN) + j
                led_letter[i] = cled.wheel(rc_index & 255)
            led_letter.write()
            sleep_ms(10)

        print("Testing A amb B buttons")
        while True:
            if button_A.value():
                led_letter[0] = (255,0,0)
            else:
                led_letter[0] = (0,0,0)

            if button_B.value():
                led_letter[1] = (255,0,0)
            else:
                led_letter[1] = (0,0,0)

            if not button_A.value() and not button_B.value():
                break

            led_letter.write()

        mySong = music(song, pins=[Pin(BUZZER_PIN)], looping=False)

        while mySong.tick():
            sleep_ms(40)

    except KeyboardInterrupt:
        print("##Hardware test aborted!##")
        return

    finally:
        led_stripe.fill( (0,0,0) )
        led_stripe.write()
        led_letter.fill( (0,0,0) )
        led_letter.write()

        # De-init the neopixel object
        del led_letter
        del led_stripe


def initBhy():
    print("Uploading firmware to BMI160")
    if not bhy.upload_BHI160B_RAM():
        print("Uploading FAILED!")
        return False

    print("Upload completed. Starging MainTask, waiting for the BMI160 to come up...")
    bhy.startMainTask()
    while not bhy.bhy_interrupt():
        pass

    sleep_ms(100)
    return True

def printSensorsList():
    my_list = []
    for i in range(1,33): # TODO: find a more reliable way to find how many sensor are available
        my_list.append(str(i) + ". " + bhy.sensorIdToName(i))

    for a,b in zip(my_list[::2],my_list[1::2]):
        print ('{:<40}{:<}'.format(a,b))

def printSensorsConfig():
    if not len(sensor_config):
        print("No sensor configured yet!\n")
    else:
        for i in range(len(sensor_config)):
            print("-"*20)
            s = sensor_config[i]
            print((str(i)+". "), end='')
            print("Sensor name:", bhy.sensorIdToName(s["sensor_id"]))
            print("\tWakeup:",s["wakeup_status"])
            print("\tSample rate:",s["sample_rate"])
            print("\tLatency ms:",s["max_report_latency_ms"])
            print("\tFlush FIFO:", end='')
            if s["flush_sensor"] == BHY.BHY_FIFO_FLUSH_ALL:
                print(" BHY_FIFO_FLUSH_ALL")
            else:
                print(" NONE")
            print("\tChange sensitivity:",s["change_sensitivity"])
            print("\tDynamic range:",s["dynamic_range"])
            print("-"*20)

    print('\n')

# Typical configuration is:
# Wakeup: FALSE
# Sample freq: 25 Hz
# Flush FIFO sensor: FALSE
# Max Report Latency: 0
# Change Sensitivity: 0
# Dynamic Range: 0

def addNewSensor():
    printSensorsList()
    id = int(input("Sensor ID: "))
    wake = input("Wakeup? [y/N]: ")
    sample = int(input("Sample rate [25]: ") or 25)
    latency = int(input("Max report latency [0]: ") or 0)
    flush_sensor = str(input("Flush Sensor data [-A-ll/-n-one]: ") or "A")
    change_sensitivity = int(input("Change Sensitivity [0]: ") or 0)
    dynamic_range = int(input("Dynamic Range [0]: ") or 0)

    if wake == 'y' or wake == 'Y':
        wake = True
    else:
        wake = False

    if flush_sensor == 'a' or flush_sensor == 'A':
        flush_sensor = BHY.BHY_FIFO_FLUSH_ALL
    else:
        flush_sensor = 0

    sensor_config.append({"sensor_id": id,
                          "wakeup_status": wake,
                          "sample_rate":sample,
                          "max_report_latency_ms": latency,
                          "flush_sensor": flush_sensor,
                          "change_sensitivity": change_sensitivity,
                          "dynamic_range": dynamic_range,
                          "to_remove": False})

    print("Sensor added!\n")

def removeSensor():
    printSensorsConfig()
    id = int(input("Sensor ID:"))
    if id >= len(sensor_config):
        print("Not a valid choice!")
    else:
        s = sensor_config[id]
        bhy.configVirtualSensor(s["sensor_id"], s["wakeup_status"], 0, 0, 0, 0, 0) # To disable a sensor, set sample reat at 0
        sensor_config.remove(s)
        print("Sensor Removed!\n")

def sensorsMenu():
    fin = False
    while not fin:
        print("### Sensors Menu ###")
        print("1. Print current configuration")
        print("2. Add a new sensor")
        print("3. Remove a sensor")
        print("4. Scan Physical Sensors")
        print("5. Calibrate Sensors")
        print("\n99. Return main menu")

        sel = input("\n> ")
        if sel == "1":
            printSensorsConfig()
        elif sel == "2":
            addNewSensor()
        elif sel == "3":
            removeSensor()
        elif sel == "4":
            scanPhysicalSensor()
        elif sel == "5":
            calibrationProccess()
        elif sel == "99":
            fin = True
        else:
          print("Bad selection!\n")

def scanPhysicalSensor():
    for i in range(33,96):
        data = bhy.readParameterPage(bhy.BHY_SYSTEM_PAGE, i, 16)
        if data:
            print("-"*20)
            print(binascii.hexlify(data))
            print("-"*20)

# TODO: Fix this function and add physical sensor query procedure
def discoverSelfTest():
    bhy.requestSelfTest()
    # Wait for interrupt
    while not bhy.bhy_interrupt():
        pass

    buffer = bhy.readFIFO()

    #print(binascii.hexlify(buffer))

    # print("Event type:", info,
    #     "\tEvent ID:", buffer[0],
    #     "\tData:", binascii.hexlify(buffer[:dim])
    #     )

    # events = bhy.parse_fifo(buffer, [BHY.EV_META_EVENTS, BHY.EV_WAKEUP_META_EVENTS])
    # for e in events:
    #     print(bhy.parseMetaEvent(e[2]))

def streamCalibration(vs_type):
    calibrated = False
    calibration_level = -1
    try:
        while not calibrated:
            # Wait for interrupt
            while not bhy.bhy_interrupt():
                pass

            buffer = bhy.readFIFO()

            events = bhy.parse_fifo(buffer, raw=True) # Dont pass the filters if we want to show everythings

            for e in events: # Loop every events read
                if e[0] == vs_type:
                    actual_level = bhy.parseVectorPlus(e[2])["accuracy"]
                    if actual_level > calibration_level:
                        calibration_level = actual_level
                        cled.drawLevel(actual_level, 3)
                        print("Level of calibration:", calibration_level)

            if calibration_level == 3:
                calibrated = True
                cled.blinkAll((255,255,255), 50, 2)
                print("Calibrated!")

        return True

    except KeyboardInterrupt:
        print("User Interrupt! Ending streaming!")
        return False

def setRemappingMatrix():
    print("Current Accelerometer map is:")
    print(bhy.getRemappingMatrix(BHY.VS_TYPE_ACCELEROMETER))
    bhy.setRemappingMatrix(BHY.VS_TYPE_ACCELEROMETER, remapping_matrix)
    print("New Accelerometer map is:")
    print(bhy.getRemappingMatrix(BHY.VS_TYPE_ACCELEROMETER))
    print("Current Megnetometer map is:")
    print(bhy.getRemappingMatrix(BHY.VS_TYPE_MAGNETIC_FIELD_UNCALIBRATED))
    bhy.setRemappingMatrix(BHY.VS_TYPE_MAGNETIC_FIELD_UNCALIBRATED, remapping_matrix)
    print("New Megnetometer map is:")
    print(bhy.getRemappingMatrix(BHY.VS_TYPE_MAGNETIC_FIELD_UNCALIBRATED))
    print("Current Gyroscope map is:")
    print(bhy.getRemappingMatrix(BHY.VS_TYPE_GYROSCOPE_UNCALIBRATED))
    bhy.setRemappingMatrix(BHY.VS_TYPE_GYROSCOPE_UNCALIBRATED, remapping_matrix)
    print("New Gyroscope map is:")
    print(bhy.getRemappingMatrix(BHY.VS_TYPE_GYROSCOPE_UNCALIBRATED))

def calibrationProccess():
    bhy.calibrated = False

    print("##This procedure will follow you to calibrate the BHI160B sensors##")
    print("\nFirst we set the remapping Matrix for the MuHack Badge pcb...")
    setRemappingMatrix()
    print("\nThen, starting from the gyroscope, lay the pcb on a flat surface:")

    bhy.configVirtualSensorWithConfig({"sensor_id": BHY.VS_TYPE_GYROSCOPE,
                                       "wakeup_status": False,
                                       "sample_rate": 200,
                                       "max_report_latency_ms": 0,
                                       "flush_sensor": 0,
                                       "change_sensitivity": 0,
                                       "dynamic_range": 0
                                       })

    if not streamCalibration(BHY.VS_TYPE_GYROSCOPE):
        print("\n##Calibration process ABORTED##\n")
        return False

    # Disable the Gyroscope
    bhy.configVirtualSensorWithConfig({"sensor_id": BHY.VS_TYPE_GYROSCOPE,
                                       "wakeup_status": False,
                                       "sample_rate": 0,
                                       "max_report_latency_ms": 0,
                                       "flush_sensor": 0,
                                       "change_sensitivity": 0,
                                       "dynamic_range": 0
                                       })
    print("Now the Accelerometer: rotate the board with 45° step in one direction")

    bhy.configVirtualSensorWithConfig({"sensor_id": BHY.VS_TYPE_ACCELEROMETER,
                                       "wakeup_status": False,
                                       "sample_rate": 200,
                                       "max_report_latency_ms": 0,
                                       "flush_sensor": 0,
                                       "change_sensitivity": 0,
                                       "dynamic_range": 0
                                       })
    if not streamCalibration(BHY.VS_TYPE_ACCELEROMETER):
        print("\n##Calibration process ABORTED##\n")
        return False

    # Disable the Accelerometer
    bhy.configVirtualSensorWithConfig({"sensor_id": BHY.VS_TYPE_ACCELEROMETER,
                                       "wakeup_status": False,
                                       "sample_rate": 0,
                                       "max_report_latency_ms": 0,
                                       "flush_sensor": 0,
                                       "change_sensitivity": 0,
                                       "dynamic_range": 0
                                       })

    print("And last, the Magnetometer: draw an 8-figure in mid-air with the board")
    bhy.configVirtualSensorWithConfig({"sensor_id": BHY.VS_TYPE_GEOMAGNETIC_FIELD,
                                       "wakeup_status": False,
                                       "sample_rate": 200,
                                       "max_report_latency_ms": 0,
                                       "flush_sensor": 0,
                                       "change_sensitivity": 0,
                                       "dynamic_range": 0
                                       })
    if not streamCalibration(BHY.VS_TYPE_GEOMAGNETIC_FIELD):
        print("\n##Calibration process ABORTED##\n")
        return False

    # Disable the Magnetometer
    bhy.configVirtualSensorWithConfig({"sensor_id": BHY.VS_TYPE_GEOMAGNETIC_FIELD,
                                       "wakeup_status": False,
                                       "sample_rate": 0,
                                       "max_report_latency_ms": 0,
                                       "flush_sensor": 0,
                                       "change_sensitivity": 0,
                                       "dynamic_range": 0
                                       })

    print("\n##Calibration completed!##\n")
    bhy.calibrated = True
    cled.clear()
    cled.np.write()

def idleAnimation():
    # startCLED() # We dont need CLED on idle
        # Activate orientation sensor
    sensor = {"sensor_id": BHY.VS_TYPE_PICKUP,
              "wakeup_status": True,
              "sample_rate": 200,
              "max_report_latency_ms": 0,
              "flush_sensor": 0,
              "change_sensitivity": 0,
              "dynamic_range": 0
             }
    bhy.configVirtualSensorWithConfig(sensor)

    sensor = {"sensor_id": BHY.VS_TYPE_WAKEUP,
              "wakeup_status": True,
              "sample_rate": 200,
              "max_report_latency_ms": 0,
              "flush_sensor": 0,
              "change_sensitivity": 0,
              "dynamic_range": 0
             }
    bhy.configVirtualSensorWithConfig(sensor)

    startCLED()

    j = 0

    fin = False

    try:
        while not fin:
            gc.collect()

            if (not button_A.value()):
                break

            # Wait for interrupt and progress the animation
            while not bhy.bhy_interrupt():
                for i in range(LED_STRIPE_LEN):
                    rc_index = (i * 256 // LED_STRIPE_LEN) + j
                    cled.np[i] = cled.wheel(rc_index & 255)

                for i in range(LED_LETTER_LEN):
                    rc_index = (i * 256 // LED_LETTER_LEN) + j
                    cled.np_letter[i] = cled.wheel(rc_index & 255)

                cled.np.write()
                cled.np_letter.write()
                sleep_ms(10)

                j += 1
                if j >= 255:
                    j = 0

            buffer = bhy.readFIFO()

            events = bhy.parse_fifo(buffer, False) # Dont pass the filters if we want to show everythings

            for e in events: # Loop every events read
                if (e[0] == BHY.VS_TYPE_PICKUP 
                    or e[0] == (BHY.VS_TYPE_PICKUP + BHY.BHY_SID_WAKEUP_OFFSET)
                    or e[0] == BHY.VS_TYPE_WAKEUP 
                    or e[0] == (BHY.VS_TYPE_WAKEUP + BHY.BHY_SID_WAKEUP_OFFSET)):
                    fin = True # We have been picked up!

    except Exception as e:
        raise e
    finally:
        stopCLED()
        # Disable orientation sensor
        sensor["sample_rate"] = 0
        bhy.configVirtualSensorWithConfig(sensor)
        cled.clear()
        cled.clearLetter()
        cled.np.write()
        cled.np_letter.write()

def accelerometer():
    # Activate orientation sensor
    sensor = {"sensor_id": BHY.VS_TYPE_LINEAR_ACCELERATION,
              "wakeup_status": False,
              "sample_rate": 25,
              "max_report_latency_ms": 0,
              "flush_sensor": 0,
              "change_sensitivity": 0,
              "dynamic_range": 0
             }
    bhy.configVirtualSensorWithConfig(sensor)

    startCLED()

    try:
        while True:
            if (not button_B.value()):
                break
            gc.collect()

            # Wait for interrupt
            while not bhy.bhy_interrupt():
                pass

            buffer = bhy.readFIFO()

            events = bhy.parse_fifo(buffer, False) # Dont pass the filters if we want to show everythings

            for e in events: # Loop every events read
                if e[0] == BHY.VS_TYPE_LINEAR_ACCELERATION or e[0] == (BHY.VS_TYPE_LINEAR_ACCELERATION + BHY.BHY_SID_WAKEUP_OFFSET):
                    cled.addAnimation(cled.ANIM_DRAW_VECTOR, [(e[2]['x'] * 4 ) / 32768, (e[2]['y'] * 4) / 32768, (e[2]['z'] * 4) / 32768, 10])
                    
    except Exception as e:
        raise e
    finally:
        stopCLED()
        # Disable orientation sensor
        sensor["sample_rate"] = 0
        bhy.configVirtualSensorWithConfig(sensor)
        

def compass():
    # Activate orientation sensor
    sensor = {"sensor_id": BHY.VS_TYPE_ORIENTATION,
              "wakeup_status": False,
              "sample_rate": 25,
              "max_report_latency_ms": 0,
              "flush_sensor": 0,
              "change_sensitivity": 0,
              "dynamic_range": 0
             }
    bhy.configVirtualSensorWithConfig(sensor)

    startCLED()

    try:
        while True:
            if (not button_B.value()):
                break
            gc.collect()

            # Wait for interrupt
            while not bhy.bhy_interrupt():
                pass

            buffer = bhy.readFIFO()

            events = bhy.parse_fifo(buffer, False) # Dont pass the filters if we want to show everythings

            for e in events: # Loop every events read
                if e[0] == BHY.VS_TYPE_ORIENTATION or e[0] == (BHY.VS_TYPE_ORIENTATION + BHY.BHY_SID_WAKEUP_OFFSET):
                    north = 360 - e[2]['x'] # Lock in place the rotation 
                    cled.addAnimation(cled.ANIM_DRAW_ARROW, north)
                    
    except Exception as e:
        raise e
    finally:
        stopCLED()
        # Disable orientation sensor
        sensor["sample_rate"] = 0
        bhy.configVirtualSensorWithConfig(sensor)
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

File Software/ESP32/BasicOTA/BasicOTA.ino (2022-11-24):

#include <WiFi.h>
#include <ESPmDNS.h>
#include <WiFiUdp.h>
#include <ArduinoOTA.h>

const char* ssid = "SSID";
const char* password = "PASSWORD";

void setup() {
  Serial.begin(115200);
  Serial.println("Booting");
  WiFi.mode(WIFI_STA);
  WiFi.begin(ssid, password);
  //bool fin = false;
  while (true) {
    if(WiFi.waitForConnectResult() != WL_CONNECTED){
      fin = true;
      break;
    }
    Serial.println("Connection Failed! Retrying (press a key to change wifi credentials..");
    delay(2000);
    if (Serial.available() > 0) {
      Serial.print("SSID: ");
      ssid = Serial.readString();
      Serial.print("ESP32 received: ");
      Serial.println(ssid);
    }
    delay(5000);
    ESP.restart();
  }

  // Port defaults to 3232
  // ArduinoOTA.setPort(3232);

  // Hostname defaults to esp3232-[MAC]

  // No authentication by default
  // ArduinoOTA.setPassword("admin");

  // Password can be set with it's md5 value as well
  // MD5(admin) = 21232f297a57a5a743894a0e4a801fc3
  // ArduinoOTA.setPasswordHash("21232f297a57a5a743894a0e4a801fc3");

  ArduinoOTA
    .onStart([]() {
      String type;
      if (ArduinoOTA.getCommand() == U_FLASH)
        type = "sketch";
      else // U_SPIFFS
        type = "filesystem";

      // NOTE: if updating SPIFFS this would be the place to unmount SPIFFS using SPIFFS.end()
      Serial.println("Start updating " + type);
    })
    .onEnd([]() {
      Serial.println("\nEnd");
    })
    .onProgress([](unsigned int progress, unsigned int total) {
      Serial.printf("Progress: %u%%\r", (progress / (total / 100)));
    })
    .onError([](ota_error_t error) {
      Serial.printf("Error[%u]: ", error);
      if (error == OTA_AUTH_ERROR) Serial.println("Auth Failed");
      else if (error == OTA_BEGIN_ERROR) Serial.println("Begin Failed");
      else if (error == OTA_CONNECT_ERROR) Serial.println("Connect Failed");
      else if (error == OTA_RECEIVE_ERROR) Serial.println("Receive Failed");
      else if (error == OTA_END_ERROR) Serial.println("End Failed");
    });

  ArduinoOTA.begin();

  Serial.println("Ready");
  Serial.print("IP address: ");
  Serial.println(WiFi.localIP());
}

int last = 0;
int incomingByte = 0;
void loop() {
  if (millis() - last > 1000){
    last = millis();
    Serial.printf("Progress: %u\r", last);
  }

  if (Serial.available() > 0) {
    
    incomingByte = Serial.read();
    Serial.print("ESP32 received: ");
    Serial.println(incomingByte);
  }
  ArduinoOTA.handle();
}

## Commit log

2022-10-26 First Commit - version 1.0
    [Badge.kicad_pcb, Badge.kicad_sch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]
2022-10-27 Added SAOv2 Connector - re-arranged some RP pins connection
    [Badge.kicad_pcb, Badge.kicad_sch]
2022-10-27 Connected both USB-C data signal, moved the crystal - revisisted ready for production
    [Badge-CuBottom.gbr, Badge-CuTop.gbr, Badge-EdgeCuts.gbr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]
2022-11-24 First BOSS commit, added BasicOTA (not working), updated Hardware .gitignore
    [BasicOTA.ino, cled.py, example.py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]
2022-11-25 Improved the headless mode, CLED system and minor bug fix - UNSATBLE
    [cled.py, main.py]
2022-11-25 Headless mode is working, added idle animation - there are still some bugs with CLED
    [cled.py, main.py]
